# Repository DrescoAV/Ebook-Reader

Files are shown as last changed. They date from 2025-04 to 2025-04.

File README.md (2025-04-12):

# OpenBook Reader  
**Autor:** Andrei-Valerian Andreescu  
**Grupa:** 335CC  

## Diagrama bloc

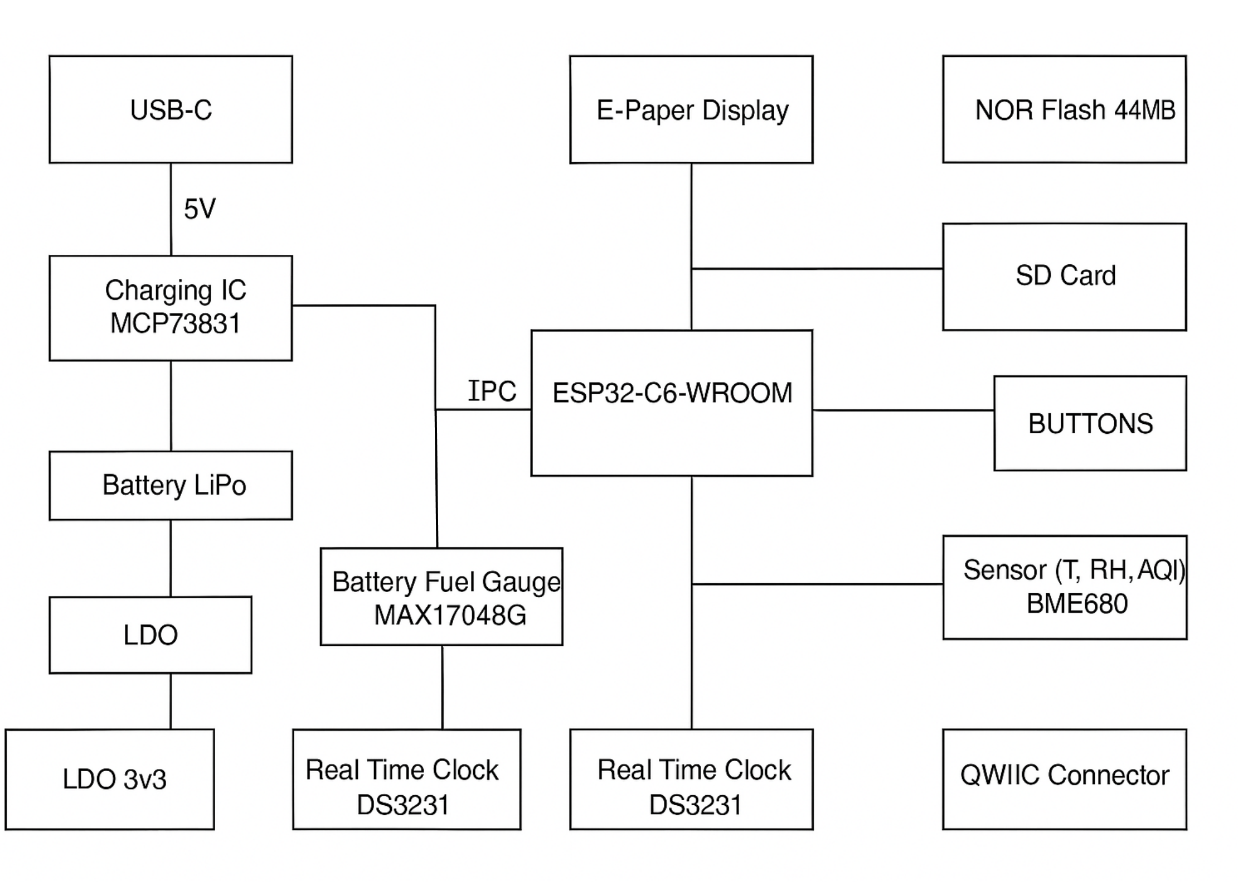
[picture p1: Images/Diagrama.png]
Block Diagram


---

## Bill Of  Materials (BOM)
| Component Name | Link | Datasheet Link |
|---|---|---|
| 112ATAARR03ATTEND | [Link](https://store.comet.srl.ro/Catalogue/Product/43497/) | [Link](https://www.attend.com.tw/data/download/file/112A-TAAR-R03.rar) |
| ADAFRUIT_CHIP-LED0603 | [Link](https://www.snapeda.com/parts/KP-1608SURCK/Kingbright/view-part/?ref=search&t=LED%200603) | [Link](https://www.snapeda.com/parts/KP-1608SURCK/Kingbright/datasheet/) |
| CAPCP3225X100N | [Link](https://www.snapeda.com/parts/CPH3225A/Seiko+Instruments/view-part/?ref=eda) | [Link](https://www.snapeda.com/parts/CPH3225A/Seiko%20Instruments/datasheet/) |
| DIOC1608X36N | [Link](https://www.snapeda.com/parts/PGB1010603MR/Littelfuse/view-part/?ref=eda) | [Link](https://www.snapeda.com/parts/PGB1010603MR/Littelfuse%20Inc./datasheet/) |
| EAGLE-LTSPICE_C0402 | [Link](https://componentsearchengine.com/part-view/CC0402MRX5R5BB106/YAGEO) | [Link](https://componentsearchengine.com/Datasheets/2/CC0402MRX5R5BB106.pdf) |
| ESP32_WROVER_AVX---SD0805S020S1R0_AVX_0  | [Link](https://ro.mouser.com/ProductDetail/KYOCERA-AVX/SD0805S020S1R0?qs=jCA%252BPfw4LHbpkAoSnwrdjw%3D%3D)  | [Link](https://ro.mouser.com/datasheet/2/40/schottky-3165252.pdf) |
| ESP32_WROVER_BME680_PSON80P300X300X100-8N| [Link](https://www.snapeda.com/parts/BME680/Bosch/view-part/?welcome=home) | [Link](https://www.snapeda.com/parts/BME680/Bosch%20Sensortec/datasheet/) |
| ESP32_WROVER_EAGLE-LTSPICE_C0402 | [Link](https://componentsearchengine.com/part-view/CC0402MRX5R5BB106/YAGEO) | [Link](https://componentsearchengine.com/Datasheets/2/CC0402MRX5R5BB106.pdf) |
| ESP32_WROVER_EAGLE-LTSPICE_R0402 | [Link](https://componentsearchengine.com/part-view/R0402%201%25%20100%20K%20(RC0402FR-07100KL)/YAGEO) | [Link](https://www.yageo.com/upload/media/product/products/datasheet/rchip/PYu-RC_Group_51_RoHS_L_12.pdf)|
| ESP32_WROVER_SPARKFUN-DISCRETESEMI_SOT23-3| [Link](https://componentsearchengine.com/part-view/DMG2305UX-7/Diodes%20Incorporated) | [Link](https://www.diodes.com//assets/Datasheets/DMG2305UX.pdf) |
| ESP32_WROVER_SPARKFUN-IC-POWER_SOT23-5 | [Link](https://ro.mouser.com/ProductDetail/Microchip-Technology/MCP73831T-5ACI-OT?qs=hH%252BOa0VZEiAcgAcEkuamXg%3D%3D) | [Link](https://ro.mouser.com/datasheet/2/268/MCP73831_Family_Data_Sheet_DS20001984H-3441711.pdf) |
| ESP32C6_VARISTOR_CT/CN1812 | [Link](https://ro.mouser.com/ProductDetail/EPCOS-TDK/B72520T0350K062?qs=dEfas%2FXlABIszF52uu7vrg%3D%3D) | [Link](https://www.tdk-electronics.tdk.com/inf/75/db/CTVS_14/Surge_protection_series.pdf) |
| FH34SRJ24S05SH99 | [Link](https://ro.mouser.com/ProductDetail/Hirose-Connector/FH34SRJ-24S-0.5SH99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) | [Link](https://ro.mouser.com/datasheet/2/185/FH34SRJ_24S_0_5SH_99__CL0580_1255_6_99_2DDrawing_0-1615044.pdf)|
| IND_4828-WE-TPC_WRE | [Link](https://ro.mouser.com/ProductDetail/Wurth-Elektronik/744043680?qs=PGXP4M47uW6VkZq%252BkzjrHA%3D%3D)  | [Link](https://www.we-online.com/components/products/datasheet/744043680.pdf) |
| JST04_1MM_RA | [Link](https://ro.mouser.com/ProductDetail/Adafruit/4208?qs=PzGy0jfpSMtbScLbr0L5dw%3D%3D) | [Link](https://ro.mouser.com/ProductDetail/Adafruit/4208?qs=PzGy0jfpSMtbScLbr0L5dw%3D%3D) |
| MYBUTTON | [Link](https://industry.panasonic.com/global/en/products/control/switch/light-touch/number/evqpuj02k) | [Link](https://industry.panasonic.com/global/en/downloads?tab=catalog&small_g_cd=203&part_no=EVQPUJ02K)  |
| RCL_CT3528 | [Link](https://www.snapeda.com/parts/TAJB475K025RNJ/AVX/view-part/?t=capacitor%203528&con_ref=None) | [Link](https://www.snapeda.com/parts/TAJB475K025RNJ/AVX/datasheet/) |
| SAMACSYS_PARTS_USB4110GFA | [Link](https://componentsearchengine.com/part-view/USB4110-GF-A/GCT%20(GLOBAL%20CONNECTOR%20TECHNOLOGY)) | [Link](https://gct.co/files/drawings/usb4110.pdf) |
| SOD3716X135N | [Link](https://ro.mouser.com/ProductDetail/KYOCERA-AVX/SD0805S020S1R0?qs=jCA%252BPfw4LHbpkAoSnwrdjw%3D%3D)  | [Link](https://ro.mouser.com/datasheet/2/40/schottky-3165252.pdf) |
| SOIC127P1032X265-16N | [Link](https://eu.mouser.com/ProductDetail/Wurth-Elektronik/744043680?qs=PGXP4M47uW6VkZq%252BkzjrHA%3D%3D)  | [Link](https://www.snapeda.com/parts/DS3231SN%23/Analog%20Devices/datasheet/) |
| SON127P600X800X80-9N | [Link](https://www.snapeda.com/parts/W25Q512JVEIQ/Winbond+Electronics/view-part/?ref=eda) | [Link](https://www.snapeda.com/parts/W25Q512JVEIQ/Winbond%20Electronics/datasheet/) |
| SON50P200X200X80-9N | [Link](https://www.snapeda.com/parts/MAX17048G+T10/Analog+Devices/view-part/?ref=eda) | [Link](https://www.snapeda.com/parts/MAX17048G+T10/Analog%20Devices/datasheet/) |
| SOT65P210X110-3N | [Link](https://componentsearchengine.com/part-view/SI1308EDL-T1-GE3/Vishay) | [Link](https://componentsearchengine.com/Datasheets/1/SI1308EDL-T1-GE3.pdf) |
| SOT95P280X125-5N | [Link](https://componentsearchengine.com/part-view/BD5229G-TR/ROHM%20Semiconductor) | [Link](https://datasheet.datasheetarchive.com/originals/distributors/Datasheets_SAMA/f2b9741ef86007909f138d561a359946.pdf) |
| SOT95P280X145-6N | [Link](https://www.snapeda.com/parts/USBLC6-2SC6Y/STMicroelectronics/view-part/?ref=eda) | [Link](https://www.snapeda.com/parts/USBLC6-2SC6Y/STMicroelectronics/datasheet/) |
| XCVR_ESP32-C6-WROOM-1-N8 | [Link](https://www.snapeda.com/parts/ESP32-C6-WROOM-1-N8/Espressif+Systems/view-part/?ref=eda) | [Link](https://www.snapeda.com/parts/ESP32-C6-WROOM-1-N8/Espressif%20Systems/datasheet/) |
| Screen | [Link](https://grabcad.com/library/7-5in-e-ink-display-assortment-1) | [Link](https://grabcad.com/library/7-5in-e-ink-display-assortment-1) |
| Battery | Custom Made Model | [Link](https://www.tme.eu/Document/e0683d8c34e6d878124489f71bffb6ee/cel0014.pdf) |
| Case | [Download](https://ocw.cs.pub.ro/courses/_media/tsc/openbook_enclosure.zip) | Not Provided |

---

# Descriere detaliata a functionalitatii hardware

### Componente si interfete

Proiectul utilizeaza urmatoarele componente principale:

- **ESP32-C6 WROOM**: Microcontroller principal ce gestioneaza comunicarea, procesarea datelor si interfatarea tuturor componentelor.
- **Display E-Ink Waveshare 1.5”**: Se conecteaza prin interfata SPI la ESP32, afisand informatii precum ora, data, temperatura si alte notificari.
- **SD Card Reader**: Conectat prin SPI pentru stocarea si accesarea datelor suplimentare.
- **USB-C & Charger MCP73832**: Gestioneaza incarcarea bateriei LiPo si furnizeaza alimentare stabila catre sistem.
- **Baterie LiPo**: Alimentare portabila pentru intregul sistem.
- **Senzor BME688**: Conectat prin I2C, monitorizeaza temperatura, umiditatea si calitatea aerului.
- **RTC DS3231SN**: Conectat prin I2C, mentine timpul real si data exacta chiar si fara alimentare principala.
- **Butoane GPIO**: Reset, Boot si Change pentru diverse functii si moduri operationale ale ESP32.

### Specificatii de comunicatie

- **SPI**: Utilizata pentru Display-ul E-Ink si modulul SD Card.
- **I2C**: Pentru senzorul BME688 si RTC DS3231SN.
- **GPIO**: Pentru butoane si semnale auxiliare (reset, boot).
- **USB**: Conexiune USB-C pentru incarcare si eventuala comunicare de date cu PC-ul.

### Calcul energie

- ESP32-C6: Consum activ aproximativ 100-160 mA la 3.3V
- Display E-Ink: Consum in timpul actualizarii ~15 mA, consum aproape zero in idle.
- Senzor BME688: Consum mediu 0.9 mA
- RTC DS3231SN: Consum mediu 0.2 mA
- Modul incarcare MCP73832 si circuite auxiliare: consum variabil in functie de incarcarea bateriei.

Total mediu estimat in functionare normala: ~150-200 mA la 3.3V (in actualizare), consum idle redus considerabil.

---

## Detaliere pini ESP32-C6

| Pin ESP32-C6 | Nume în schemă | Funcție hardware | Motivare / Utilizare |
|---|---|---|---|
| GPIO0 | - | - | Nu este conectat. |
| GPIO1 | - | - | Nu este conectat. |
| GPIO2 | - | - | Nu este conectat. |
| GPIO3 | RESET | Reset | Reset hardware pentru repornirea rapidă a sistemului. |
| GPIO4 | SS_SD | SPI CS (SD card) | Selectează SD card-ul pentru comunicație SPI. |
| GPIO5 | EPD_DC | SPI DC (Display) | Control între date și comandă pentru e-paper display. |
| GPIO6 | SCK | SPI CLK (comun) | Semnal de ceas SPI pentru display și SD card. |
| GPIO7 | MOSI | SPI MOSI (comun) | Trimite date către display și SD card. |
| GPIO8 | IO/BOOT (cu buton) | Boot / GPIO | Buton de boot pentru programare firmware. |
| GPIO9 | - | - | Nu este conectat. |
| GPIO10 | EPD_CS | SPI CS (Display) | Selectează e-paper display-ul pentru comunicație SPI. |
| GPIO11 | FLASH_CS | SPI CS (Flash) | Selectează memoria flash externă. |
| GPIO12 | USB_D- | USB | Linie de date USB. |
| GPIO13 | USB_D+ | USB | Linie de date USB. |
| GPIO14 | IO/CHANGE | GPIO | Buton pentru interacțiune utilizator (schimbare mod, etc). |
| GPIO15 | RXD (implicit) | UART RX | Recepție date serială. |
| GPIO16 | TXD (implicit) | UART TX | Transmisie date serială. |
| GPIO17 | - | - | Nu este conectat. |
| GPIO18 | RTC_RST | Reset RTC | Resetare modul RTC extern. |
| GPIO19 | I2C_PW | Alimentare I2C | Control alimentare pentru senzori I2C. |
| GPIO20 | EPD_3V3_C | Alimentare Display | Activează alimentarea e-paper display-ului. |
| GPIO21 | SDA | I2C SDA | Comunicare I2C pentru senzori (ex. BME688, RTC). |
| GPIO22 | SCL | I2C SCL | Semnal de ceas pentru magistrala I2C. |
| GPIO23 | EPD_RST | Reset Display | Reset e-paper display. |

---

## Imagini relevante

- Imagini relevante:

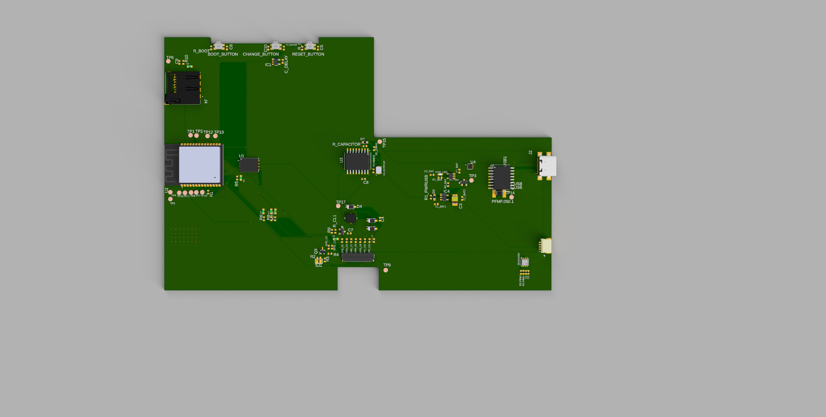
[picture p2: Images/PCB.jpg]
PCB
  - **PCB Randare**: 
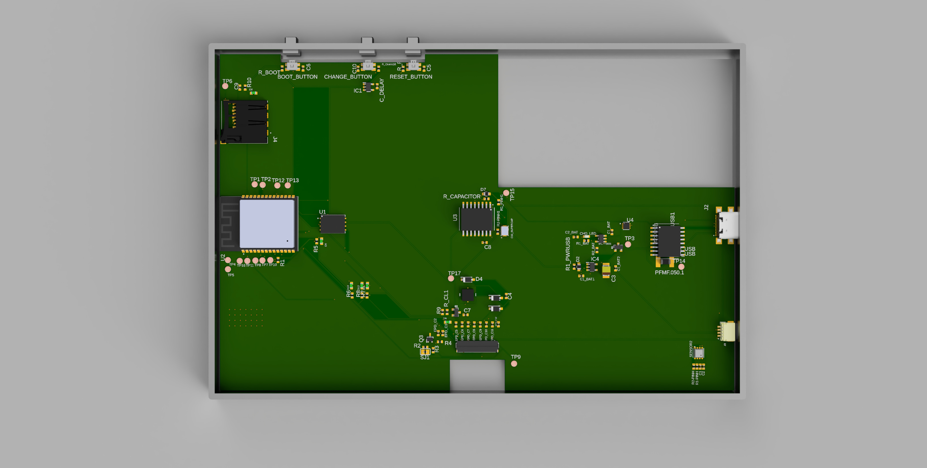
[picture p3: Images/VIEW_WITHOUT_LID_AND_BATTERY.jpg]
Carcasa si PCB
  - **Carcasa si PCB (fara capac si baterie)**: 
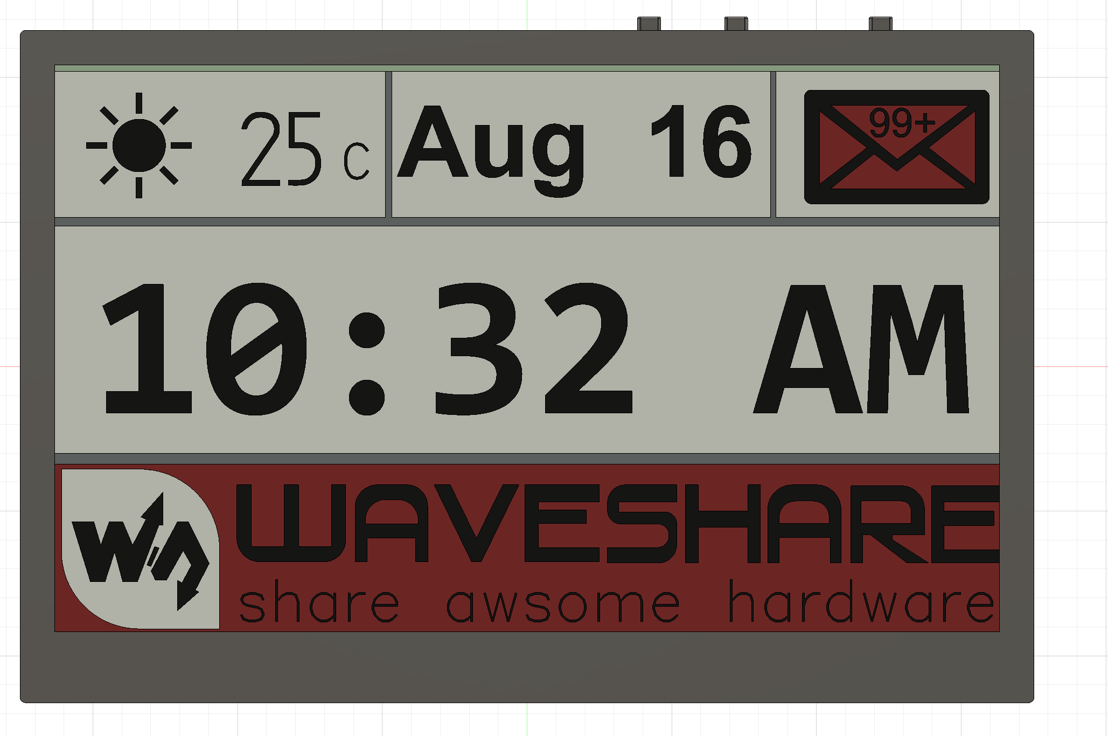
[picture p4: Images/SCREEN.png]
Display frontal
  - **Display frontal**: 
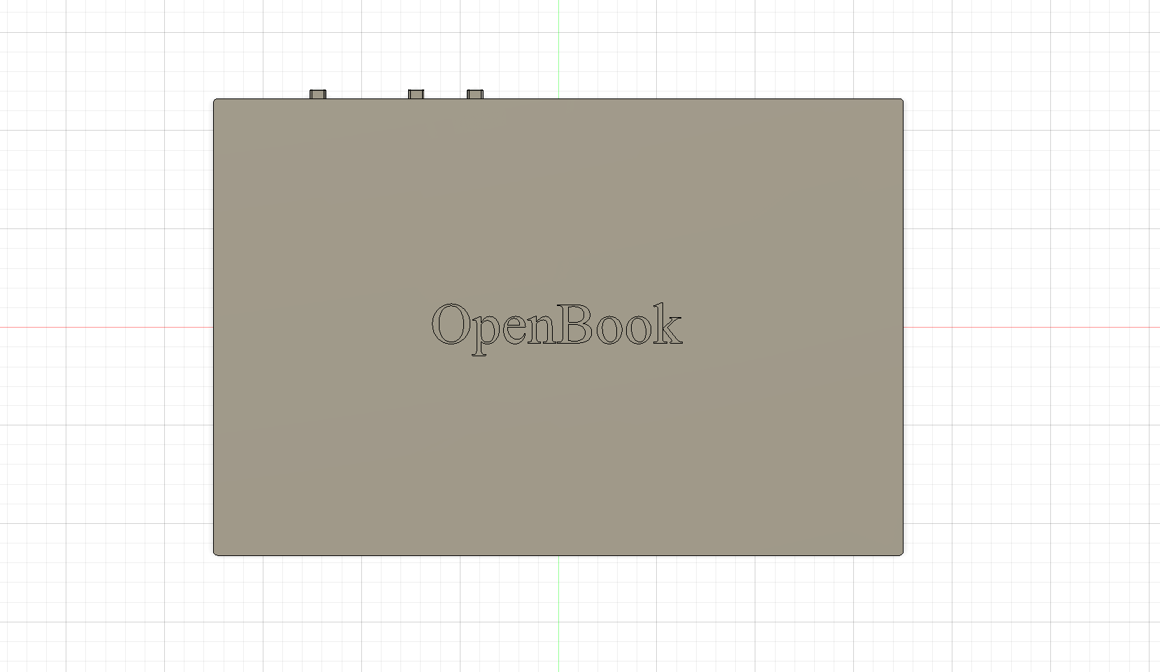
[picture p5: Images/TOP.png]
Carcasa fata
  - **Vedere carcasa din fata**: 
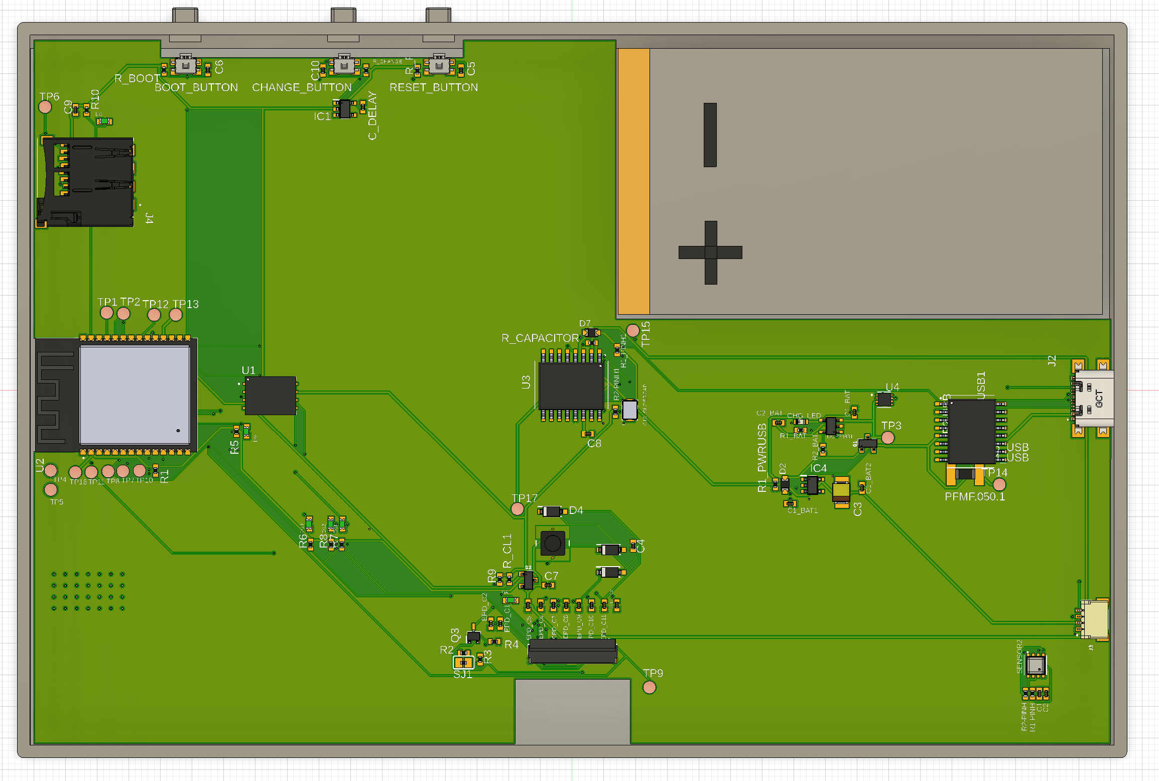
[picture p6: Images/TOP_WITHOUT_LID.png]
Carcasa deschisa
  - **Carcasa deschisa**:

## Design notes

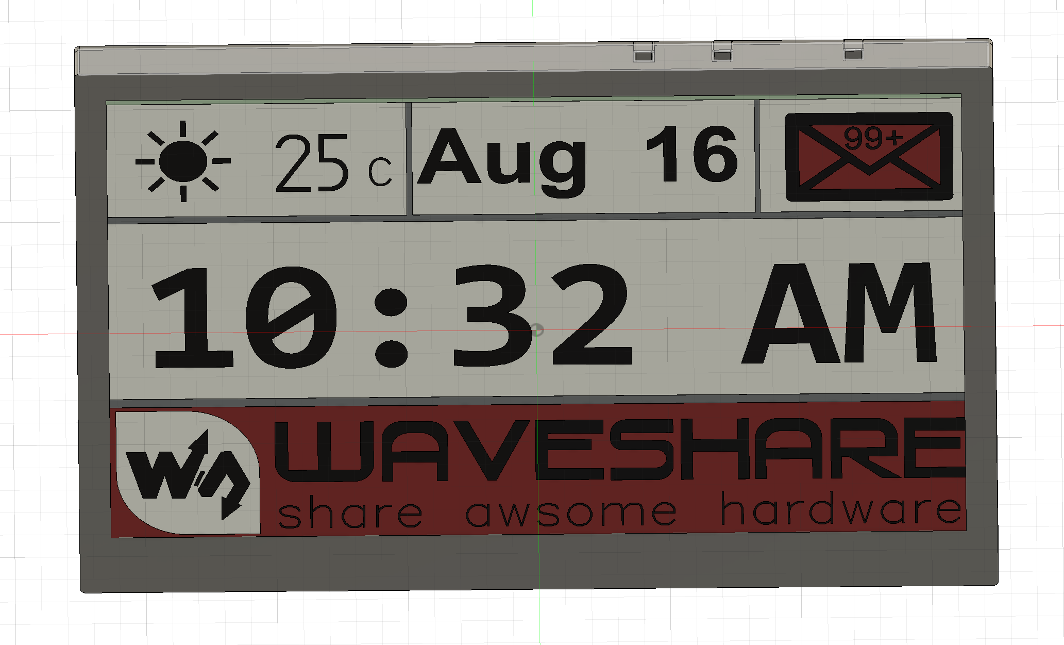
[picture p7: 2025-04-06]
Images/INCLINED.png

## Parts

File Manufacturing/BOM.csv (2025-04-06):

Qty | Value | Device | Package | Parts | Description | ARROW_PART_NUMBER | ARROW_PRICE-STOCK | ATRIBUT | AVAILABILITY | CENTROID_NOT_SPECIFIED | CHECK_PRICES | COPYRIGHT | DATASHEET | DESCRIPTION | DIGIKEY_DESCRIPTION | DIGIKEY_PART_NUMBER | HEIGHT | LEAD_FREE | MANUFACTURER_NAME | MANUFACTURER_PART_NUMBER | MF | MFR_NAME | MOUSER_PART_NUMBER | MOUSER_PRICE-STOCK | MOUSER_TESTING_PART_NUMBER | MOUSER_TESTING_PRICE-STOCK | MP | MPN | PACKAGE | POPULARITY | PREFIX | PRICE | PROD_ID | PURCHASE-URL | ROHS | SNAPEDA_LINK | SPICEMODEL | SPICEPREFIX | TEMPERATURE_RANGE_HIGH | TEMPERATURE_RANGE_LOW | TP_SIGNAL_NAME | VALUE | VALUE_DISPLAY
1 |  | ADAFRUIT_LEDCHIP-LED0603 | ADAFRUIT_CHIP-LED0603 | CHG_LED | LED
1 |  | SJ | SJ | SJ1 | SMD solder JUMPER |  |  |  |  |  |  |  |  |  |  |  |  |  |  |  |  |  |  |  |  |  |  |  |  | 3
1 | 0.1uF/50V | ESP32_WROVER_EAGLE-LTSPICE_CC0402 | ESP32_WROVER_EAGLE-LTSPICE_C0402 | EPD_C5 | CAPACITOR, European symbol |  |  |  |  |  |  |  |  |  |  |  |  |  |  |  |  |  |  |  |  |  |  |  |  |  |  |  |  |  |  |  | NONE | C
1 | 0.47 | ESP32_WROVER_EAGLE-LTSPICE_RR0402 | ESP32_WROVER_EAGLE-LTSPICE_R0402 | R3 | RESISTOR, European symbol |  |  |  |  |  |  |  |  |  |  |  |  |  |  |  |  |  |  |  |  |  |  |  |  |  |  |  |  |  |  |  | NONE | R
1 | 100K | ESP32_WROVER_EAGLE-LTSPICE_RR0402 | ESP32_WROVER_EAGLE-LTSPICE_R0402 | R1_PWRUSB | RESISTOR, European symbol |  |  |  |  |  |  |  |  |  |  |  |  |  |  |  |  |  |  |  |  |  |  |  |  |  |  |  |  |  |  |  | NONE | R
2 | 100nF | EAGLE-LTSPICE_CC0402 | EAGLE-LTSPICE_C0402 | C4_USB, C9 | CAPACITOR, European symbol |  |  |  |  |  |  |  |  |  |  |  |  |  |  |  |  |  |  |  |  |  |  |  |  |  |  |  |  |  |  |  | NONE | C
6 | 100nF | ESP32_WROVER_EAGLE-LTSPICE_CC0402 | ESP32_WROVER_EAGLE-LTSPICE_C0402 | C1, C2, C6, C8, C10, C_DELAY | CAPACITOR, European symbol |  |  |  |  |  |  |  |  |  |  |  |  |  |  |  |  |  |  |  |  |  |  |  |  |  |  |  |  |  |  |  | NONE | C
1 | 100uF TANT | RCL_CPOL-EUCT3528 | RCL_CT3528 | C3 | POLARIZED CAPACITOR, European symbol |  |  |  |  |  |  |  |  |  |  |  |  |  |  |  |  |  |  |  |  |  |  |  |  | 0 |  |  |  |  |  |  |  | C
15 | 10K | ESP32_WROVER_EAGLE-LTSPICE_RR0402 | ESP32_WROVER_EAGLE-LTSPICE_R0402 | R1-PINH, R1_PINH1, R2-PINH, R2-PINH1, R4, R5, R6, R7, R8, R9, R10, R_BOOT, R_CHANGE, R_CL1, R_RESET | RESISTOR, European symbol |  |  |  |  |  |  |  |  |  |  |  |  |  |  |  |  |  |  |  |  |  |  |  |  |  |  |  |  |  |  |  | NONE | R
1 | 10k | ESP32_WROVER_EAGLE-LTSPICE_RR0402 | ESP32_WROVER_EAGLE-LTSPICE_R0402 | R1 | RESISTOR, European symbol |  |  |  |  |  |  |  |  |  |  |  |  |  |  |  |  |  |  |  |  |  |  |  |  |  |  |  |  |  |  |  | NONE | R
1 | 10uF | ESP32_WROVER_EAGLE-LTSPICE_CC0402 | ESP32_WROVER_EAGLE-LTSPICE_C0402 | C7 | CAPACITOR, European symbol |  |  |  |  |  |  |  |  |  |  |  |  |  |  |  |  |  |  |  |  |  |  |  |  |  |  |  |  |  |  |  | NONE | C
1 | 112A-TAAR-R03_ATTEND | 112A-TAAR-R03_ATTEND | 112ATAARR03ATTEND | J4 | Micro SD Card Socket, Push-Push Type, Top Mount, SMT, H=1.83mm, 10u |  |  |  |  |  |  |  |  | Micro SD Card Socket | Push-Push Type | Top Mount | SMT | H=1.83mm | 10u |  |  | 1.9mm |  | ATTEND | 112A-TAAR-R03 ATTEND
1 | 15 | ESP32_WROVER_EAGLE-LTSPICE_RR0402 | ESP32_WROVER_EAGLE-LTSPICE_R0402 | R_CAPACITOR | RESISTOR, European symbol |  |  |  |  |  |  |  |  |  |  |  |  |  |  |  |  |  |  |  |  |  |  |  |  |  |  |  |  |  |  |  | NONE | R
1 | 1uF | ESP32_WROVER_EAGLE-LTSPICE_CC0402 | ESP32_WROVER_EAGLE-LTSPICE_C0402 | C5 | CAPACITOR, European symbol |  |  |  |  |  |  |  |  |  |  |  |  |  |  |  |  |  |  |  |  |  |  |  |  |  |  |  |  |  |  |  | NONE | C
9 | 1uF/50V | ESP32_WROVER_EAGLE-LTSPICE_CC0402 | ESP32_WROVER_EAGLE-LTSPICE_C0402 | EPD_C1, EPD_C2, EPD_C6, EPD_C7, EPD_C8, EPD_C9, EPD_C10, EPD_C11, EPD_C12 | CAPACITOR, European symbol |  |  |  |  |  |  |  |  |  |  |  |  |  |  |  |  |  |  |  |  |  |  |  |  |  |  |  |  |  |  |  | NONE | C
1 | 2.2 | ESP32_WROVER_EAGLE-LTSPICE_RR0402 | ESP32_WROVER_EAGLE-LTSPICE_R0402 | R2 | RESISTOR, European symbol |  |  |  |  |  |  |  |  |  |  |  |  |  |  |  |  |  |  |  |  |  |  |  |  |  |  |  |  |  |  |  | NONE | R
1 | 200 | ESP32_WROVER_EAGLE-LTSPICE_RR0402 | ESP32_WROVER_EAGLE-LTSPICE_R0402 | R1_BAT | RESISTOR, European symbol |  |  |  |  |  |  |  |  |  |  |  |  |  |  |  |  |  |  |  |  |  |  |  |  |  |  |  |  |  |  |  | NONE | R
1 | 20V/4.2A/52mO/1.4W | ESP32_WROVER_SPARKFUN-DISCRETESEMI_MOSFET_PCH-DMG2305UX-7 | ESP32_WROVER_SPARKFUN-DISCRETESEMI_SOT23-3 | Q1 | P-channel MOSFETs |  |  |  |  |  |  |  |  |  |  |  |  |  |  |  |  |  |  |  |  |  |  |  |  |  |  |  | TRAN-14388 |  |  |  |  |  |  |  |  | 20V/4.2A/52mO/1.4W
1 | 20V/4.2A/52mO/1.4W | ESP32_WROVER_SPARKFUN-DISCRETESEMI_MOSFET_PCH-DMG2305UX-7 | ESP32_WROVER_SPARKFUN-DISCRETESEMI_SOT23-3 | Q2 | P-channel MOSFETs |  |  | DMG2305UX-7 |  |  |  |  |  |  |  |  |  |  |  |  |  |  |  |  |  |  |  |  |  |  |  |  | TRAN-14388 |  |  |  |  |  |  |  |  | 20V/4.2A/52mO/1.4W
1 | 2K | ESP32_WROVER_EAGLE-LTSPICE_RR0402 | ESP32_WROVER_EAGLE-LTSPICE_R0402 | R2_BAT | RESISTOR, European symbol |  |  |  |  |  |  |  |  |  |  |  |  |  |  |  |  |  |  |  |  |  |  |  |  |  |  |  |  |  |  |  | NONE | R
5 | 4.7uF | EAGLE-LTSPICE_CC0402 | EAGLE-LTSPICE_C0402 | C1_BAT, C1_BAT1, C1_BAT2, C2_BAT, C5_USB | CAPACITOR, European symbol |  |  |  |  |  |  |  |  |  |  |  |  |  |  |  |  |  |  |  |  |  |  |  |  |  |  |  |  |  |  |  | NONE | C
1 | 4.7uF/25V | ESP32_WROVER_EAGLE-LTSPICE_CC0402 | ESP32_WROVER_EAGLE-LTSPICE_C0402 | C4 | CAPACITOR, European symbol |  |  |  |  |  |  |  |  |  |  |  |  |  |  |  |  |  |  |  |  |  |  |  |  |  |  |  |  |  |  |  | NONE | C
2 | 5k1 | ESP32_WROVER_EAGLE-LTSPICE_RR0402 | ESP32_WROVER_EAGLE-LTSPICE_R0402 | R2-USB, R2-USB1 | RESISTOR, European symbol |  |  |  |  |  |  |  |  |  |  |  |  |  |  |  |  |  |  |  |  |  |  |  |  |  |  |  |  |  |  |  | NONE | R
1 | 68uH | 744043680IND_4828-WE-TPC_WRE | IND_4828-WE-TPC_WRE | L1 |  |  |  |  |  |  |  | Copyright (C) 2024 Ultra Librarian. All rights reserved. |  |  |  |  |  |  |  | 744043680 |  | Wurth Electronics
1 | BD5229G-TR | BD5229G-TR | SOT95P280X120-5N | IC1 | Voltage Detector with Adjustable Delay Time: CMOS processes are utilized to develop high precision, low current consumption CMOS reset ICs that allow arbitrary setting of the delay time. The extensive lineup includes both Nch Open Drain and CMOS output types in a wide range of detection voltages (from 2.3V to 6.0V, in 0.1V steps), enabling selection of the ideal solution based on customer requirements. In addition, the entire series is of course both lead-free and RoHS-compliant. |  |  |  |  |  |  |  |  | Voltage Detector with Adjustable Delay Time: CMOS processes are utilized to develop high precision | low current consumption CMOS reset ICs that allow arbitrary setting of the delay time. The extensive lineup includes both Nch Open Drain and CMOS output types in a wide range of detection voltages (from 2.3V to 6.0V | in 0.1V steps) | enabling selection of the ideal solution based on customer requirements. In addition | the entire series is of course both lead-free and RoHS-compliant. |  |  | 1.25mm |  | ROHM Semiconductor | BD5229G-TR |  |  | 755-BD5229G-TR | https://www.mouser.co.uk/ProductDetail/ROHM-Semiconductor/BD5229G-TR?qs=4kLU8WoGk0vvnhrrYwdszw%3D%3D
1 | BME688 | ESP32_WROVER_BME680_BME680 | ESP32_WROVER_BME680_PSON80P300X300X100-8N | SENSOR2 | Integrated Environmental Unit |  |  |  | Unavailable |  |  |  |  | Integrated Environmental Unit |  |  |  |  |  |  | Bosch Sensortec |  |  |  |  |  | BME680 |  | LGA-8 Bosch Tools |  |  | None
3 | BUTTON_CUSYOMV1 | BUTTON_CUSYOMV1 | MYBUTTON | BOOT_BUTTON, CHANGE_BUTTON, RESET_BUTTON
1 | CPH3225A | CPH3225A | CAPCP3225X100N | C10_SUPERCAP | Cap 0.011F 3.3V 1210 Flat Check availability |  |  |  | Not in stock |  | https://www.snapeda.com/parts/CPH3225A/Seiko+Instruments/view-part/?ref=eda |  |  | 11 mF (EDLC) Supercapacitor 3.3 V 1210 (3225 Metric) - - |  |  |  |  |  |  | Seiko Instruments |  |  |  |  |  | CPH3225A |  | 1210 Seiko |  |  | None |  | https://www.snapeda.com/api/url_track_click_mouser/?unipart_id=562593&manufacturer=Seiko Instruments&part_name=CPH3225A&search_term=None |  | https://www.snapeda.com/parts/CPH3225A/Seiko+Instruments/view-part/?ref=snap
1 | DS3231SN# | DS3231SN# | SOIC127P1032X265-16N | U3 | Real Time Clock Serial 16-Pin SOIC W T/R Check availability |  |  |  | In Stock |  | https://www.snapeda.com/parts/DS3231SN%23/Analog+Devices/view-part/?ref=eda |  |  | Extremely Accurate I²C-Integrated RTC/TCXO/Crystal |  |  |  |  |  |  | Analog Devices |  |  |  |  |  | DS3231SN# |  | SOIC-16 Maxim |  |  | None |  | https://www.snapeda.com/api/url_track_click_mouser/?unipart_id=99048&manufacturer=Analog Devices&part_name=DS3231SN#&search_term=None |  | https://www.snapeda.com/parts/DS3231SN%23/Analog+Devices/view-part/?ref=snap
1 | ESP32-C6-WROOM-1-N8 | ESP32-C6-WROOM-1-N8 | XCVR_ESP32-C6-WROOM-1-N8 | U2 | Check availability |  |  |  | In Stock |  | https://www.snapeda.com/parts/ESP32-C6-WROOM-1-N8/Espressif+Systems/view-part/?ref=eda |  |  | Multiprotocol Modules ESP32-C6 module | Wi-Fi 6 in 2.4 GHz band | Bluetooth 5 | Zigbee 3.0 and Thread. ESP34-WROOM Compatible - ENGINEERING SAMPLE |  |  |  |  |  |  | Espressif Systems |  |  |  |  |  | ESP32-C6-WROOM-1-N8 |  | None |  |  | None |  |  |  | https://www.snapeda.com/parts/ESP32-C6-WROOM-1-N8/Espressif+Systems/view-part/?ref=snap
1 | ESP32C6_VARISTORCN1812 | ESP32C6_VARISTORCN1812 | ESP32C6_VARISTOR_CT/CN1812 | PFMF.050.1 | VARISTOR |  |  |  |  |  |  |  |  |  |  |  |  |  |  |  |  |  |  |  |  |  |  |  |  | 0
1 | ESP32_WROVER_AVX---SD0805S020S1R0_AVX_SD0805S020S1R0_0_0AVX_SD0805S020S1R0_0_0 | ESP32_WROVER_AVX---SD0805S020S1R0_AVX_SD0805S020S1R0_0_0AVX_SD0805S020S1R0_0_0 | ESP32_WROVER_AVX---SD0805S020S1R0_AVX_SD0805S020S1R0_0 | D7 | Schottky Barrier Rectifier Diode |  |  |  |  | No |  |  | http://datasheets.avx.com/schottky.pdf |  | DIODE SCHOTTKY 20V 1A 0805 | 478-7800-1-ND |  | yes |  |  | AVX |  | 581-SD0805S020S1R0 |  |  |  |  |  | 0805 (2012 metric) |  | D |  |  |  | yes |  |  |  | +125°C | -55°C
1 | ESP32_WROVER_SPARKFUN-IC-POWER_MCP73831 | ESP32_WROVER_SPARKFUN-IC-POWER_MCP73831 | ESP32_WROVER_SPARKFUN-IC-POWER_SOT23-5 | MCP73831 | MCP73831T Li-Ion, Li-Pol Controller |  |  |  |  |  |  |  |  |  |  |  |  |  |  |  |  |  |  |  |  |  |  |  |  |  |  |  | IC-09995
1 | FH34SRJ-24S-0.5SH_99_ | FH34SRJ-24S-0.5SH_99_ | FH34SRJ24S05SH99 | J1 | (0.50mm) Surface Mount, Right Angle |  |  |  |  |  |  |  |  | 24 Position FFC | FPC Connector Contacts | (0.50mm) Surface Mount | Right Angle |  |  | 1.1mm |  | Hirose | FH34SRJ-24S-0.5SH(99) |  |  | 798-FH34SRJ24S05SH99 | https://www.mouser.co.uk/ProductDetail/Hirose-Connector/FH34SRJ-24S-0.5SH99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
1 | MAX17048G+T10 | MAX17048G+T10 | SON50P200X200X80-9N | U4 | Check availability |  |  |  | In Stock |  | https://www.snapeda.com/parts/MAX17048G+T10/Analog+Devices/view-part/?ref=eda |  |  | 3µA 1-Cell/2-Cell Fuel Gauge with ModelGauge |  |  |  |  |  |  | Analog Devices |  |  |  |  |  | MAX17048G+T10 |  | TDFN-8 Maxim |  |  | None |  | https://www.snapeda.com/api/url_track_click_mouser/?unipart_id=329239&manufacturer=Analog Devices&part_name=MAX17048G+T10&search_term=None |  | https://www.snapeda.com/parts/MAX17048G+T10/Analog+Devices/view-part/?ref=snap
3 | MBR0530 | MBR0530 | SOD3716X135N | D3, D4, D5 | ON SEMICONDUCTOR - MBR0530 - DIODE, SCHOTTKY, 0.5A, 30V, SOD-123 |  |  |  | In Stock |  | https://www.snapeda.com/parts/MBR0530/Onsemi/view-part/?ref=eda |  |  | Diode Schottky 30 V 500mA Surface Mount SOD-123 |  |  |  |  |  |  | ON Semiconductor |  |  |  |  |  | MBR0530 |  | SOD-123-2 ON Semiconductor |  |  | None |  | https://www.snapeda.com/api/url_track_click_mouser/?unipart_id=179458&manufacturer=ON Semiconductor&part_name=MBR0530&search_term=None |  | https://www.snapeda.com/parts/MBR0530/Onsemi/view-part/?ref=snap
6 | PGB1010603MR | PGB1010603MR | DIOC1608X36N | D6, D8, D9, D10, D11, D12 | Check availability |  |  |  | In Stock |  | https://www.snapeda.com/parts/PGB1010603MR/Littelfuse/view-part/?ref=eda |  |  | 150V (Typ) Clamp - Ipp Tvs Diode Surface Mount 0603 (1608 Metric) |  |  |  |  |  |  | Littelfuse Inc. |  |  |  |  |  | PGB1010603MR |  | 0603 Littelfuse Inc. |  |  | None |  | https://www.snapeda.com/api/url_track_click_mouser/?unipart_id=5659453&manufacturer=Littelfuse Inc.&part_name=PGB1010603MR&search_term=None |  | https://www.snapeda.com/parts/PGB1010603MR/Littelfuse/view-part/?ref=snap
1 | QWIIC_RIGHT_ANGLE | QWIIC_CONNECTORJS-1MM | JST04_1MM_RA | J3 | SparkFun I2C Standard Qwiic Connector |  |  |  |  |  |  |  |  |  |  |  |  |  |  |  |  |  |  |  |  |  |  |  |  |  |  |  | CONN-13694 |  |  |  |  |  |  |  |  | QWIIC_RIGHT_ANGLE
1 | SAMACSYS_PARTS_USB4110-GF-A | SAMACSYS_PARTS_USB4110-GF-A | SAMACSYS_PARTS_USB4110GFA | J2 | CONN USB 2.0 TYPE-C R/A SMT |  |  |  |  |  |  |  |  | CONN USB 2.0 TYPE-C R/A SMT |  |  | 3.26mm |  | GCT (GLOBAL CONNECTOR TECHNOLOGY) | USB4110-GF-A |  |  | 640-USB4110-GF-A | https://www.mouser.co.uk/ProductDetail/GCT/USB4110-GF-A?qs=KUoIvG%2F9IlYiZvIXQjyJeA%3D%3D
1 | SD0805S020S1R0 | ESP32_WROVER_AVX---SD0805S020S1R0_AVX_SD0805S020S1R0_0_0AVX_SD0805S020S1R0_0_0 | ESP32_WROVER_AVX---SD0805S020S1R0_AVX_SD0805S020S1R0_0 | D2 | Schottky Barrier Rectifier Diode |  |  |  |  | No |  |  | http://datasheets.avx.com/schottky.pdf |  | DIODE SCHOTTKY 20V 1A 0805 | 478-7800-1-ND |  | yes |  |  | AVX |  | 581-SD0805S020S1R0 |  |  |  |  |  | 0805 (2012 metric) |  | D |  |  |  | yes |  |  |  | +125°C | -55°C |  |  | SD0805S020S1R0
1 | SI1308EDL-T1-GE3 | SI1308EDL-T1-GE3 | SOT65P210X110-3N | Q3 | MOSFET N-Ch 30V 1.5A TrenchFET SC70 Vishay Si1308EDL-T1-GE3 N-channel MOSFET Transistor, 1.5 A, 30 V, 3-Pin SC-70 |  |  |  | In Stock |  | https://www.snapeda.com/parts/SI1308EDL-T1-GE3/Vishay+Siliconix/view-part/?ref=eda |  |  | Si1308EDL-T1-GE3 N-channel MOSFET Transistor | 1.5 A | 30 V | 3-Pin SC-70 | Siliconix / Vishay SI1308EDL-T1-GE3 |  |  |  |  |  |  | Vishay Siliconix |  |  |  |  |  | SI1308EDL-T1-GE3 |  | SOT-323 Vishay Semiconductor |  |  | None |  | https://www.snapeda.com/api/url_track_click_mouser/?unipart_id=274603&manufacturer=Vishay Siliconix&part_name=SI1308EDL-T1-GE3&search_term=None |  | https://www.snapeda.com/parts/SI1308EDL-T1-GE3/Vishay+Siliconix/view-part/?ref=snap
17 | TPTP20R | TPTP20R | TP20R | TP1, TP2, TP3, TP4, TP5, TP6, TP7, TP8, TP9, TP10, TP11, TP12, TP13, TP14, TP15, TP16, TP17 | Test pad |  |  |  |  |  |  |  |  |  |  |  |  |  |  |  |  |  |  |  |  |  |  |  |  | 2
1 | USBLC6-2SC6Y | USBLC6-2SC6Y | SOIC127P1032X265-16N | D1 | Low Cap. ESD Protection Auto SOT-23-6 STMicroelectronics USBLC6-2SC6Y, Dual Uni-Directional TVS Diode Array, 6-Pin SOT-23 |  |  |  | In Stock |  | https://www.snapeda.com/parts/USBLC6-2SC6Y/STMicroelectronics/view-part/?ref=eda |  |  | 17V Clamp 5A (8/20µs) Ipp Tvs Diode Surface Mount SOT-23-6 |  |  |  |  |  |  | STMicroelectronics |  |  |  |  |  | USBLC6-2SC6Y |  | SOT-23-6 STMicroelectronics |  |  | None |  |  |  | https://www.snapeda.com/parts/USBLC6-2SC6Y/STMicroelectronics/view-part/?ref=snap
1 | W25Q512JVEIQ | W25Q512JVEIQ | SON127P600X800X80-9N | U1 | Check availability |  |  |  | In Stock |  | https://www.snapeda.com/parts/W25Q512JVEIQ/Winbond+Electronics/view-part/?ref=eda |  |  | FLASH - NOR Memory IC 512Mb (64M x 8) SPI - Quad I/O 133 MHz 8-WSON (8x6) |  |  |  |  |  |  | Winbond Electronics |  |  |  |  |  | W25Q512JVEIQ |  | Package |  |  | None |  |  |  | https://www.snapeda.com/parts/W25Q512JVEIQ/Winbond+Electronics/view-part/?ref=snap
1 | XC6220A331MR-G | XC6220A331MR-G | SOT95P280X120-5N | IC4 | LDO Voltage Regulators |  |  |  |  |  |  |  |  | LDO Voltage Regulators |  |  | 1.2mm |  | Torex | XC6220A331MR-G |  |  | 865-XC6220A331MR-G | https://www.mouser.co.uk/ProductDetail/Torex-Semiconductor/XC6220A331MR-G?qs=AsjdqWjXhJ8ZSWznL1J0gg%3D%3D

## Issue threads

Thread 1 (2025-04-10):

Incorrect BOM table in README

CristianSLazar, 2025-04-10:
Resolve the following problems with the bill of materials table:

- missing component BD5229G-TR
- 112ATAARR03ATTEND:
	- datasheet link leads to purchase website, not datasheet
- EAGLE-LTSPICE_C0402:
	- cannot purchase product from link
	- missing links for capacitors for every capacitance/voltage rating used in project #
- ESP32_WROVER_EAGLE-LTSPICE_R0402:
	- cannot purchase product from link
	- missing links for resistors for every resistance used in project
- MYBUTTON:
	- cannot purchase product from link
- SON127P600X800X80-9N:
	- used footprint/packege name instead of component name (W25Q512JVEIQ)
	- purchase link doesn't lead to the pricing tab, but validation tab
- DIOC1608X36N:
	- used footprint/package name instead of component name (PGB1010603MR)
- IND_4828-WE-TPC_WRE:
	- used footprint/package name instead of component name (744043680)
- FH34SRJ24S05SH99:
	- component name concatenated, instead of FH34SRJ-24S-0.5SH(99)
	- cannot purchase product from link
- SOIC127P1032X265-16N:
	- used footprint/packege name instead of component name (DS3231SN#)
	- purchase link doesn't lead to the pricing tab, but validation tab
- CAPCP3225X100N:
	- used footprint/packege name instead of component name (CPH3225A)
- SOD3716X135N:
	- used footprint/packege name instead of component name (MBR0530)
- SAMACSYS_PARTS_USB4110GFA:
	- cannot purchase product from link
- JST04_1MM_RA:
	- used footprint/packege name instead of component name ("Qwiic connector" or "Adafruit 4208")
	- datasheet link lead to the wrong datasheet (USB4110)
- SOT95P280X120-5N:
	- used footprint/packege name instead of component name (XC6220A331MR-G)
	- cannot purchase product from link
- ESP32_WROVER_BME680_PSON80P300X300X100-8N:
	- used footprint/packege name instead of component name (BME680)
	- purchase link doesn't lead to the pricing tab, but validation tab
- ESP32C6_VARISTOR_CT/CN1812:
	- component capsule is 1206 instead of 1812
- SOT95P280X145-6N:
	- used footprint/packege name instead of component name (USBLC6-2SC6Y)
- RCL_CT3528:
	- capacitance is 4.7uF instead of 100uF
- SON50P200X200X80-9N:
	- used footprint/packege name instead of component name (MAX17048G+T10)
- ADAFRUIT_CHIP-LED0603:
	- link leads to an LED not made by Adafruit
- SOT65P210X110-3N:
	- used footprint/packege name instead of component name (SI1308EDL-T1-GE3)
	- purchase link doesn't lead to the pricing tab, but validation tab

Closed 2025-04-12.

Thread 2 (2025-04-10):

Missing components from BOM in README

CristianSLazar, 2025-04-10:
The components not part of the PCB are missing from bill of materials table:

- e-paper display
- battery
- product casing

Closed 2025-04-12.

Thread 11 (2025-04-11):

Component too close to pcb edge

CristianSLazar, 2025-04-11:
Move component J4 slightly away from the pcb edge, to avoid smd pad being directly on the edge.

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

Closed 2025-04-12.

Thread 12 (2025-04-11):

Thick PCB board

CristianSLazar, 2025-04-11:
Modify PCB board thickness to be 1 mm, according to product casing specifications. This is done from the layer manager in the pcb board file.

Closed 2025-04-13.

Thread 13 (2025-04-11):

3d model overlaps

CristianSLazar, 2025-04-11:
Resolve following overlaps between 3d models in OpenBook Enclosure file:

* Between battery and e-paper display

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

* Between SD card connector and product casing

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

* Between ESP32 C6 antenna and product casing

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

* Between e-paper display and product casing

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

<br>
<br>

You can utilize the "section analysis" tool from the "inspect" tab:

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

Closed 2025-04-13.

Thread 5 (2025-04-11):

Schematic Overlapping attributes

CristianSLazar, 2025-04-11:
* Fix overlap of PFMF.050.1 value and GND, and J2 value and D1:
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

* Fix overlap between RESET_BUTTON, BOOT_BUTTON and CHANGE_BUTTON values on the respective button symbol:
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

Closed 2025-04-12.

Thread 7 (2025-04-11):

DRC errors

CristianSLazar, 2025-04-11:
Resolve the "acute angle" and "silkscreen clearance" errors.

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

To view these errors, select "Design rules" from "Rules" tab [1], and check the boxes highlighted in [2].

[1]:

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

[2]:

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

Closed 2025-04-13.

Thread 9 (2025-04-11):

Utilize via stitching

CristianSLazar, 2025-04-11:
* For connecting the ground planes, replace regular vias with via stitching wherever possible.
* To avoid situations such as [1], use via stitching to connect the ground planes.

[1]:

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

Closed 2025-04-13.

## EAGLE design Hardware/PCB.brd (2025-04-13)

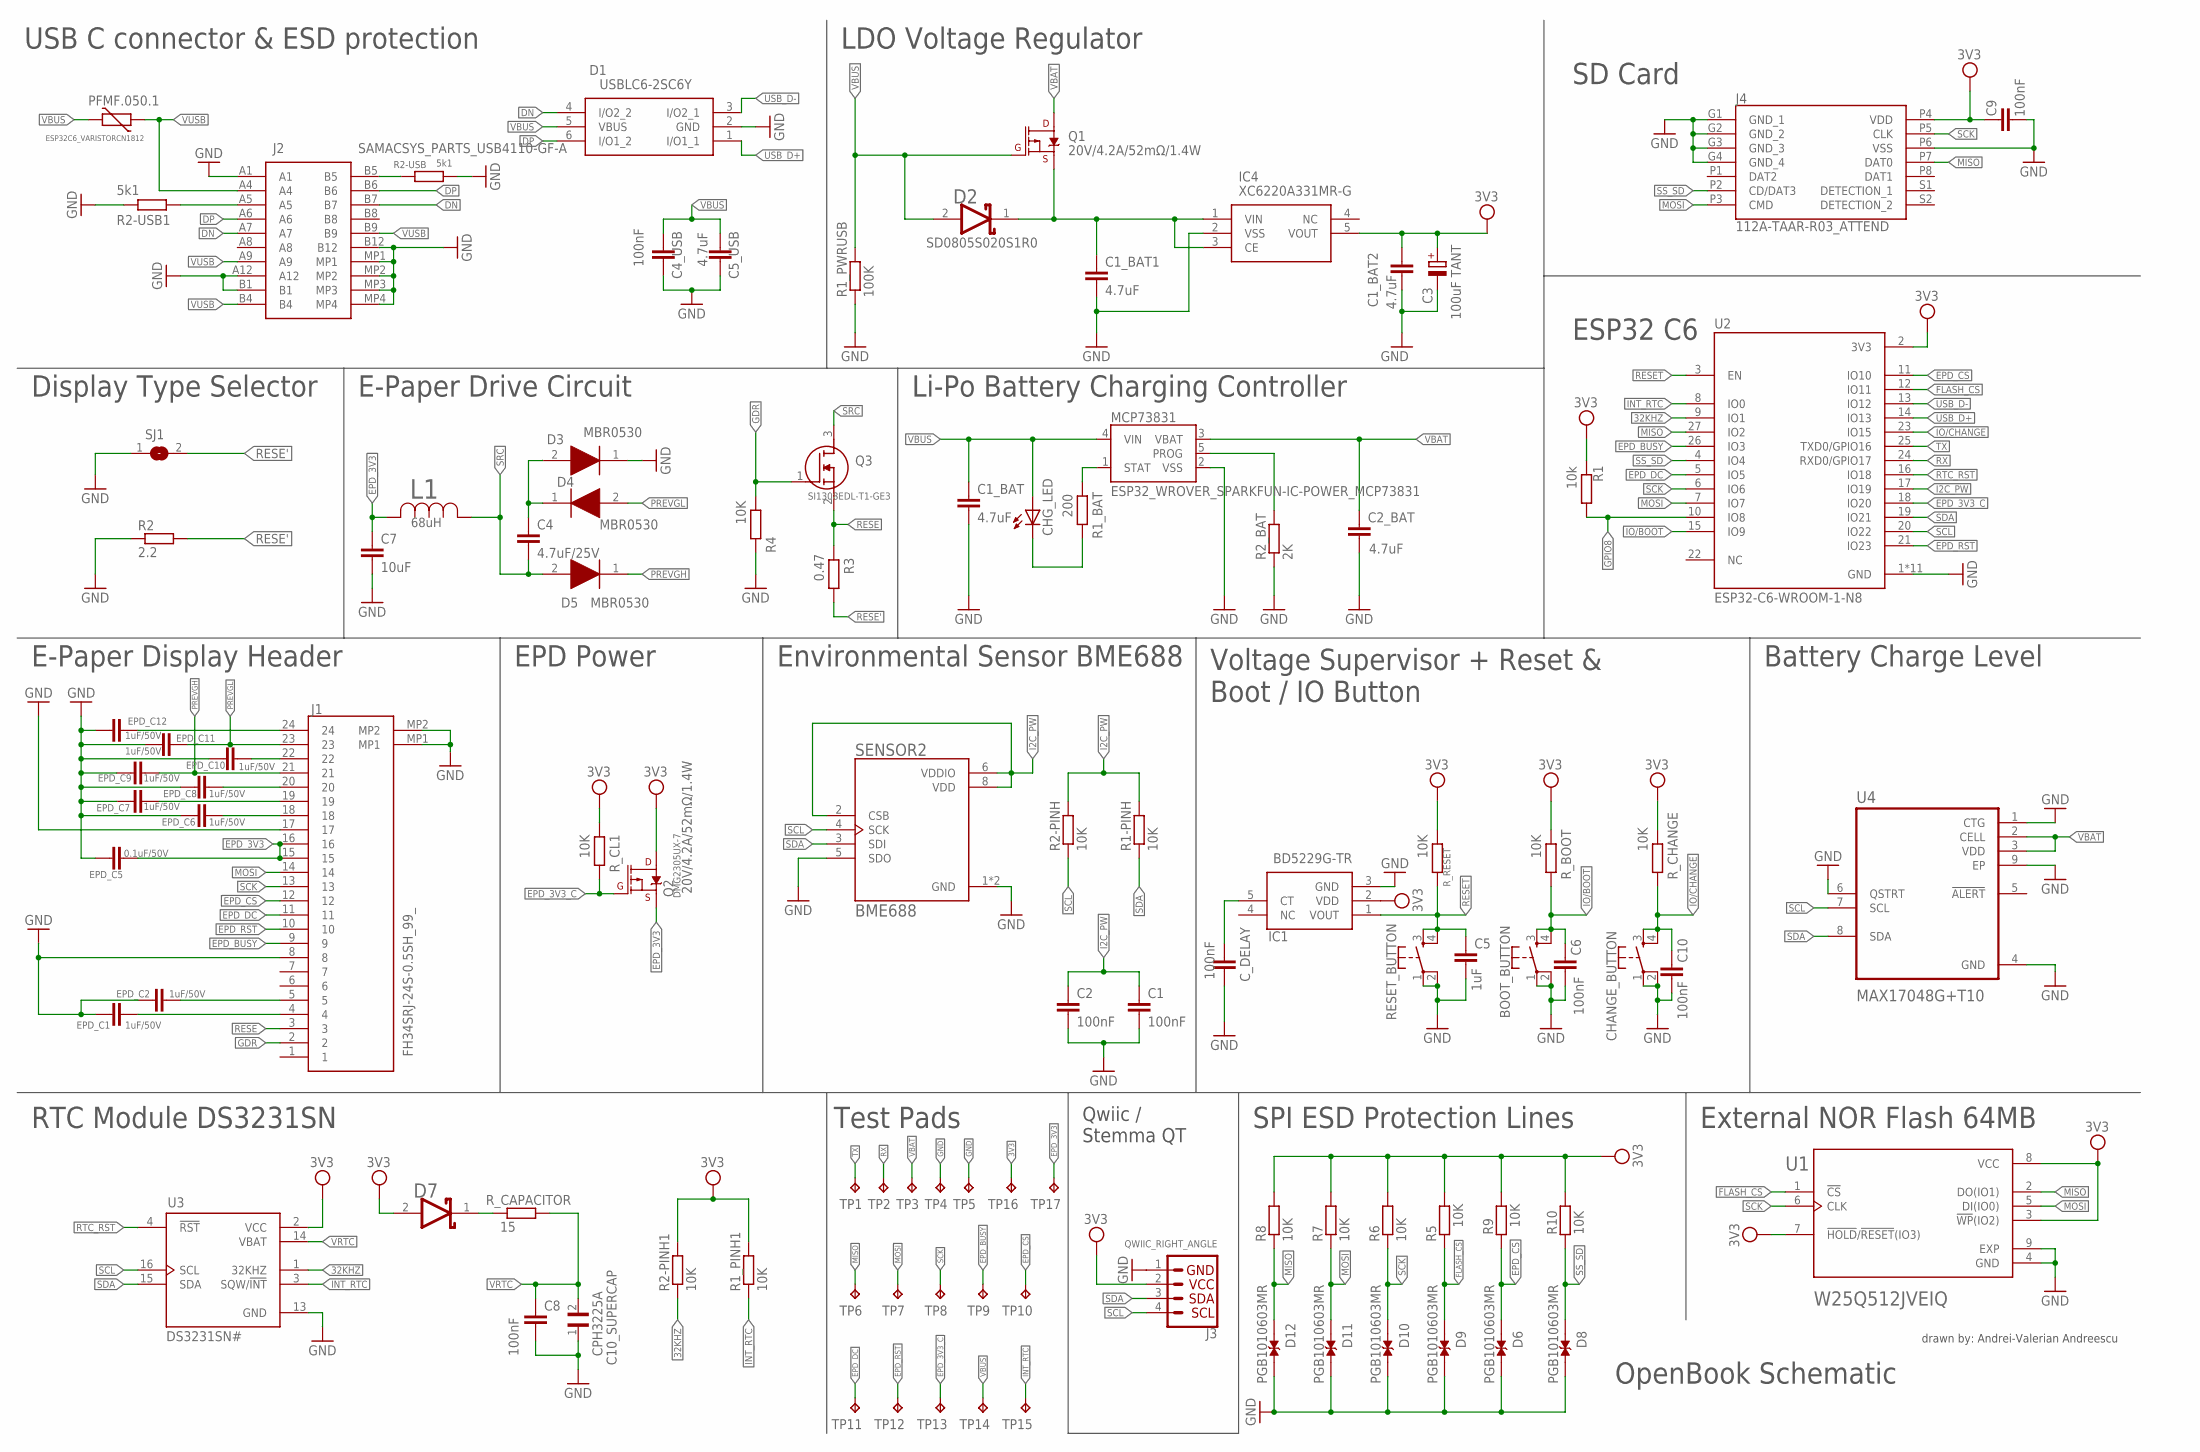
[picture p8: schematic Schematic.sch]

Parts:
BOOT_BUTTON: BUTTON_CUSYOMV1; MYBUTTON
C1, C2, C6, C8, C10: 100nF; ESP32_WROVER_EAGLE-LTSPICE_C0402
C1_BAT, C1_BAT1, C1_BAT2, C2_BAT, C5_USB: 4.7uF; EAGLE-LTSPICE_C0402
C3: 100uF TANT; RCL_CT3528
C4: 4.7uF/25V; ESP32_WROVER_EAGLE-LTSPICE_C0402
C4_USB, C9: 100nF; EAGLE-LTSPICE_C0402
C5: 1uF; ESP32_WROVER_EAGLE-LTSPICE_C0402
C7: 10uF; ESP32_WROVER_EAGLE-LTSPICE_C0402
C10_SUPERCAP: CPH3225A; CAPCP3225X100N
CHANGE_BUTTON: BUTTON_CUSYOMV1; MYBUTTON
CHG_LED: ADAFRUIT_LEDCHIP-LED0603; ADAFRUIT_CHIP-LED0603
C_DELAY: 100nF; ESP32_WROVER_EAGLE-LTSPICE_C0402
D1: USBLC6-2SC6Y; SOIC127P1032X265-16N
D2: SD0805S020S1R0; ESP32_WROVER_AVX---SD0805S020S1R0_AVX_SD0805S020S1R0_0
D3, D4, D5: MBR0530; SOD3716X135N
D6, D8, D9, D10, D11, D12: PGB1010603MR; DIOC1608X36N
D7: ESP32_WROVER_AVX---SD0805S020S1R0_AVX_SD0805S020S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; ESP32_WROVER_AVX---SD0805S020S1R0_AVX_SD0805S020S1R0_0
EPD_C1, EPD_C2, EPD_C6, EPD_C7, EPD_C8, EPD_C9, EPD_C10, EPD_C11, EPD_C12: 1uF/50V; ESP32_WROVER_EAGLE-LTSPICE_C0402
EPD_C5: 0.1uF/50V; ESP32_WROVER_EAGLE-LTSPICE_C0402
IC1: BD5229G-TR; SOT95P280X120-5N
IC4: XC6220A331MR-G; SOT95P280X120-5N
J1: FH34SRJ-24S-0.5SH_99_; FH34SRJ24S05SH99
J2: SAMACSYS_PARTS_USB4110-GF-A; SAMACSYS_PARTS_USB4110GFA
J3: QWIIC_RIGHT_ANGLE; JST04_1MM_RA
J4: 112A-TAAR-R03_ATTEND; 112ATAARR03ATTEND
L1: 68uH; IND_4828-WE-TPC_WRE
MCP73831: ESP32_WROVER_SPARKFUN-IC-POWER_MCP73831; ESP32_WROVER_SPARKFUN-IC-POWER_SOT23-5
PFMF.050.1: ESP32C6_VARISTORCN1812; ESP32C6_VARISTOR_CT/CN1812
Q1, Q2: 20V/4.2A/52mΩ/1.4W; ESP32_WROVER_SPARKFUN-DISCRETESEMI_SOT23-3
Q3: SI1308EDL-T1-GE3; SOT65P210X110-3N
R1: 10k; ESP32_WROVER_EAGLE-LTSPICE_R0402
R1-PINH, R1_PINH1, R2-PINH, R2-PINH1, R4, R5, R6, R7, R8, R9, R10: 10K; ESP32_WROVER_EAGLE-LTSPICE_R0402
R1_BAT: 200; ESP32_WROVER_EAGLE-LTSPICE_R0402
R1_PWRUSB: 100K; ESP32_WROVER_EAGLE-LTSPICE_R0402
R2: 2.2; ESP32_WROVER_EAGLE-LTSPICE_R0402
R2-USB, R2-USB1: 5k1; ESP32_WROVER_EAGLE-LTSPICE_R0402
R2_BAT: 2K; ESP32_WROVER_EAGLE-LTSPICE_R0402
R3: 0.47; ESP32_WROVER_EAGLE-LTSPICE_R0402
RESET_BUTTON: BUTTON_CUSYOMV1; MYBUTTON
R_BOOT: 10K; ESP32_WROVER_EAGLE-LTSPICE_R0402
R_CAPACITOR: 15; ESP32_WROVER_EAGLE-LTSPICE_R0402
R_CHANGE: 10K; ESP32_WROVER_EAGLE-LTSPICE_R0402
R_CL1: 10K; ESP32_WROVER_EAGLE-LTSPICE_R0402
R_RESET: 10K; ESP32_WROVER_EAGLE-LTSPICE_R0402
SENSOR2: BME688; ESP32_WROVER_BME680_PSON80P300X300X100-8N
SJ1: SJ
TP1, TP2, TP3, TP4, TP5, TP6, TP7, TP8, TP9, TP10, TP11, TP12, TP13, TP14, TP15, TP16, TP17: TPTP20R; TP20R
U1: W25Q512JVEIQ; SON127P600X800X80-9N
U2: ESP32-C6-WROOM-1-N8; XCVR_ESP32-C6-WROOM-1-N8
U3: DS3231SN#; SOIC127P1032X265-16N
U4: MAX17048G+T10; SON50P200X200X80-9N

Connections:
3V3: C1_BAT2.1, C3.+, C9.2, D7.2 (ANODE), IC1.2 (VDD), IC4.5 (VOUT), J3.2, J4.P4 (VDD), Q2.3 (D), R1.2, R1_PINH1.2, R2-PINH1.2, R5.2, R6.2, R7.2, R8.2, R9.2, R10.2, R_BOOT.2, R_CHANGE.2, R_CL1.2, R_RESET.2, TP16.TP, U1.3 (!WP!(IO2)), U1.7 (!HOLD!/!RESET!(IO3)), U1.8 (VCC), U2.2 (3V3), U3.2 (VCC)
32KHZ: R2-PINH1.1, U2.9 (IO1), U3.1 (32KHZ)
DN: D1.4 (I/O2_2), J2.A7, J2.B7
DP: D1.6 (I/O1_2), J2.A6, J2.B6
EPD_3V3: C7.1, EPD_C5.2, J1.15, J1.16, L1.2, Q2.2 (S), TP17.TP
EPD_3V3_C: Q2.1 (G), R_CL1.1, TP13.TP, U2.18 (IO20)
EPD_BUSY: J1.9, TP9.TP, U2.26 (IO3)
EPD_CS: D6.2, J1.12, R9.1, TP10.TP, U2.11 (IO10)
EPD_DC: J1.11, TP11.TP, U2.5 (IO5)
EPD_RST: J1.10, TP12.TP, U2.21 (IO23)
FLASH_CS: D9.2, R5.1, U1.1 (!CS), U2.12 (IO11)
GDR: J1.2, Q3.1 (G), R4.2
GND: BOOT_BUTTON.1, BOOT_BUTTON.2, C1.2, C1_BAT.2, C1_BAT1.2, C1_BAT2.2, C2.2, C2_BAT.2, C3.-, C4_USB.2, C5.2, C5_USB.2, C6.2, C7.2, C8.2, C9.1, C10.2, C10_SUPERCAP.1, CHANGE_BUTTON.1, CHANGE_BUTTON.2, C_DELAY.2, D1.2 (GND), D3.1 (K), D6.1, D8.1, D9.1, D10.1, D11.1, D12.1, EPD_C1.1, EPD_C2.1, EPD_C5.1, EPD_C6.1, EPD_C7.1, EPD_C8.1, EPD_C9.1, EPD_C10.1, EPD_C11.1, EPD_C12.1, IC1.3 (GND), IC4.2 (VSS), J1.8, J1.17, J1.MP1, J1.MP2, J2.A1, J2.A12, J2.B1, J2.B12, J2.MP1, J2.MP2, J2.MP3, J2.MP4, J3.1, J4.G1 (GND_1), J4.G2 (GND_2), J4.G3 (GND_3), J4.G4 (GND_4), J4.P6 (VSS), MCP73831.2 (VSS), R1_PWRUSB.1, R2.1, R2-USB.2, R2-USB1.1, R2_BAT.1, R4.1, RESET_BUTTON.1, RESET_BUTTON.2, SENSOR2.1 (GND), SENSOR2.5 (SDO), SENSOR2.7 (GND), SJ1.1, TP4.TP, TP5.TP, U1.4 (GND), U1.9 (EXP), U2.1 (GND), U2.28 (GND), U2.29_1 (GND), U2.29_2 (GND), U2.29_3 (GND), U2.29_4 (GND), U2.29_5 (GND), U2.29_6 (GND), U2.29_7 (GND), U2.29_8 (GND), U2.29_9 (GND), U3.13 (GND), U4.1 (CTG), U4.4 (GND), U4.6 (QSTRT), U4.9 (EP)
GPIO8: R1.1, U2.10 (IO8)
I2C_PW: C1.1, C2.1, R1-PINH.2, R2-PINH.2, SENSOR2.2 (CSB), SENSOR2.6 (VDDIO), SENSOR2.8 (VDD), U2.17 (IO19)
INT_RTC: R1_PINH1.1, TP15.TP, U2.8 (IO0), U3.3 (SQW/!INT)
IO/BOOT: BOOT_BUTTON.3, BOOT_BUTTON.4, C6.1, R_BOOT.1, U2.15 (IO9)
IO/CHANGE: C10.1, CHANGE_BUTTON.3, CHANGE_BUTTON.4, R_CHANGE.1, U2.23 (IO15)
MISO: D12.2, J4.P7 (DAT0), R8.1, TP6.TP, U1.2 (DO(IO1)), U2.27 (IO2)
MOSI: D11.2, J1.14, J4.P3 (CMD), R7.1, TP7.TP, U1.5 (DI(IO0)), U2.7 (IO7)
unnamed: C_DELAY.1, IC1.5 (CT)
unnamed: J2.A5, R2-USB1.2
unnamed: MCP73831.1 (STAT), R1_BAT.2
unnamed: C1_BAT1.1, D2.1 (CATHODE), IC4.1 (VIN), IC4.3 (CE), Q1.2 (S)
unnamed: CHG_LED.C, R1_BAT.1
unnamed: MCP73831.5 (PROG), R2_BAT.2
unnamed: EPD_C12.2, J1.24
unnamed: C4.1, D3.2 (A), D4.1 (K)
unnamed: D7.1 (CATHODE), R_CAPACITOR.1
unnamed: J2.B5, R2-USB.1
unnamed: EPD_C6.2, J1.18
unnamed: EPD_C8.2, J1.20
unnamed: EPD_C7.2, J1.19
unnamed: EPD_C10.2, J1.22
unnamed: EPD_C2.2, J1.5
unnamed: EPD_C1.2, J1.4
PREVGH: D5.1 (K), EPD_C9.2, J1.21
PREVGL: D4.2 (A), EPD_C11.2, J1.23
RESE: J1.3, Q3.2 (S), R3.2
RESE': R2.2, R3.1, SJ1.2
RESET: C5.1, IC1.1 (VOUT), RESET_BUTTON.3, RESET_BUTTON.4, R_RESET.1, U2.3 (EN)
RTC_RST: U2.16 (IO18), U3.4 (!RST)
RX: TP2.TP, U2.24 (RXD0/GPIO17)
SCK: D10.2, J1.13, J4.P5 (CLK), R6.1, TP8.TP, U1.6 (CLK), U2.6 (IO6)
SCL: J3.4, R2-PINH.1, SENSOR2.4 (SCK), U2.20 (IO22), U3.16 (SCL), U4.7 (SCL)
SDA: J3.3, R1-PINH.1, SENSOR2.3 (SDI), U2.19 (IO21), U3.15 (SDA), U4.8 (SDA)
SRC: C4.2, D5.2 (A), L1.1, Q3.3 (D)
SS_SD: D8.2, J4.P2 (CD/DAT3), R10.1, U2.4 (IO4)
TX: TP1.TP, U2.25 (TXD0/GPIO16)
USB_D+: D1.1 (I/O1_1), U2.14 (IO13)
USB_D-: D1.3 (I/O2_1), U2.13 (IO12)
VBAT: C2_BAT.1, MCP73831.3 (VBAT), Q1.3 (D), TP3.TP, U4.2 (CELL), U4.3 (VDD)
VBUS: C1_BAT.1, C4_USB.1, C5_USB.1, CHG_LED.A, D1.5 (VBUS), D2.2 (ANODE), MCP73831.4 (VIN), PFMF.050.1.2, Q1.1 (G), R1_PWRUSB.2, TP14.TP
VRTC: C8.1, C10_SUPERCAP.2, R_CAPACITOR.2, U3.14 (VBAT)
VUSB: J2.A4, J2.A9, J2.B4, J2.B9, PFMF.050.1.1

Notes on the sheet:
LDO Voltage Regulator
USB C connector & ESD protection
OpenBook Schematic
SD Card
ESP32 C6
Li-Po Battery Charging Controller
E-Paper Drive Circuit
Display Type Selector
E-Paper Display Header
EPD Power
Environmental Sensor BME688
Voltage Supervisor + Reset & Boot / IO Button
Battery Charge Level
External NOR Flash 64MB
SPI ESD Protection Lines
Qwiic / Stemma QT
Test Pads
RTC Module DS3231SN
drawn by: Andrei-Valerian Andreescu

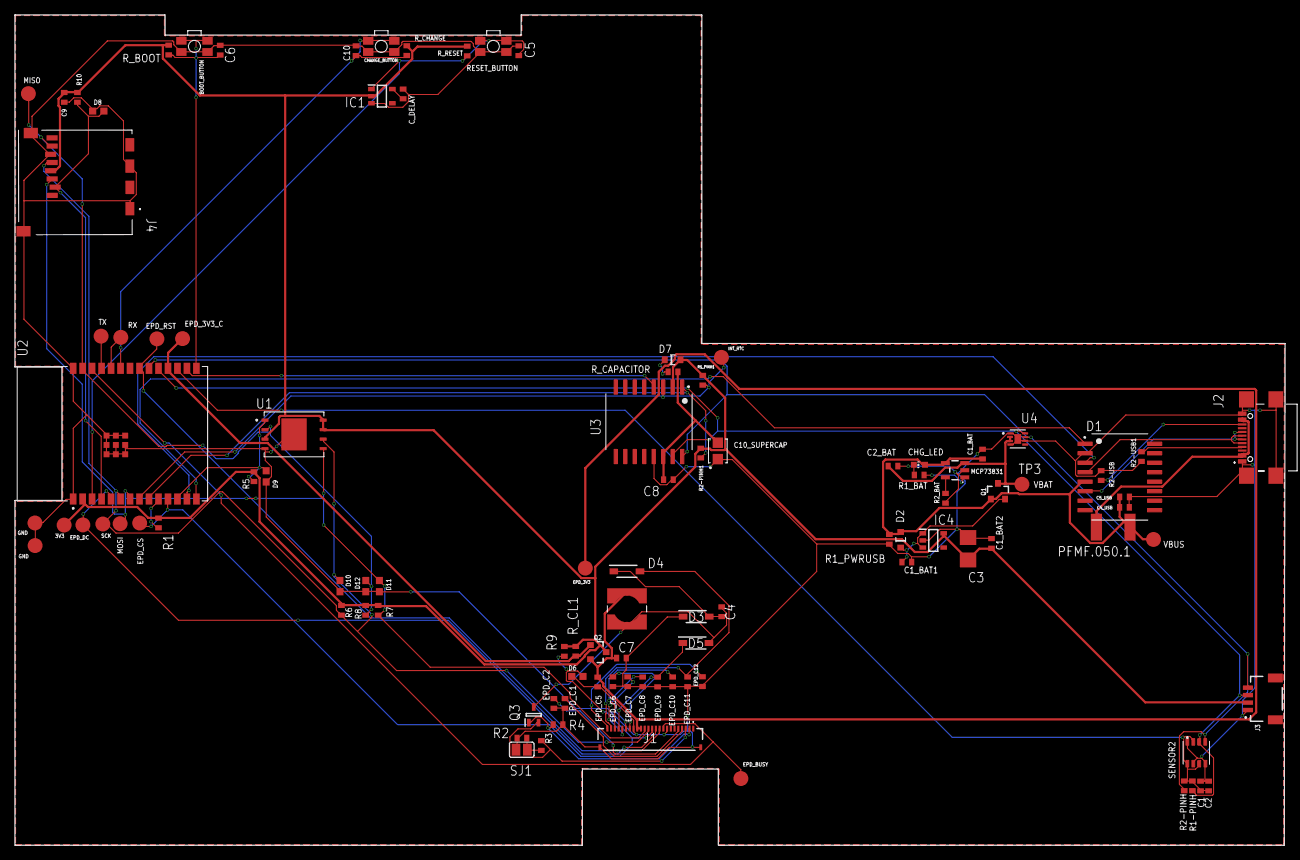
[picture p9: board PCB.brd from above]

Board: 2 copper layers, 170.1 x 111.2 mm, 103 parts (0 on the bottom side), 55 nets.

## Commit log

2025-04-12 Fixed #5.
    [Schematic.sch]
2025-04-13 Fixed #6, #7, #8, #9, #12
    [PCB.brd]

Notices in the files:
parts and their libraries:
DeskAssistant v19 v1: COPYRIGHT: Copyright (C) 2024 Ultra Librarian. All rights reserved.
